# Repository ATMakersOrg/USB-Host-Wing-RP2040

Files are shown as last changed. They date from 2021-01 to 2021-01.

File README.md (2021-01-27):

# USB-Host-Wing-RP2040
 Prototype of a USB Host Feather Wing using the RP2040
 
 Based on the excellent Feather board by Limor Fried and quite unlikely to work at the moment.  This is just a starting point to see where this could go.  
 
# Goals
 * Board should run TinyUSB (probably through Arduino when that works) to host USB peripherals.
 * Logic on this board would read the USB and then send messages to the main feather via UART (by default) or I2C or SPI with appropriate solder jumpers set
 * Voltage on the USB Host port should be 5V even when the Feather is being powered by a battery, so an onboard boost converter is needed.
 
# Current Challenges
  * Layout is ineffecient (and there are probably conflicts, etc.
  * Room in the center could be used to expose additional GPIO or Analog pins (which would be handy)
  * It would be nice to have second rows of headers to allow connections from GPIO on this wing to the main feather.
  * Power on the USB-C connector is probably wrong... I need to think through how to handle programming vs hosting w/it.
  * The Boost converter I found (PCA9411) has a BGA package which would be hard to solder (and I know nothing about it) - looking to replace with MCP1642B-50 which is easier to solder & seems like a better fit.
  * The MISO and MOSI lines should not be swapped ( need to redo them)
 
 I welcome all input (including thoughts about killing this idea)!
 Bill
 
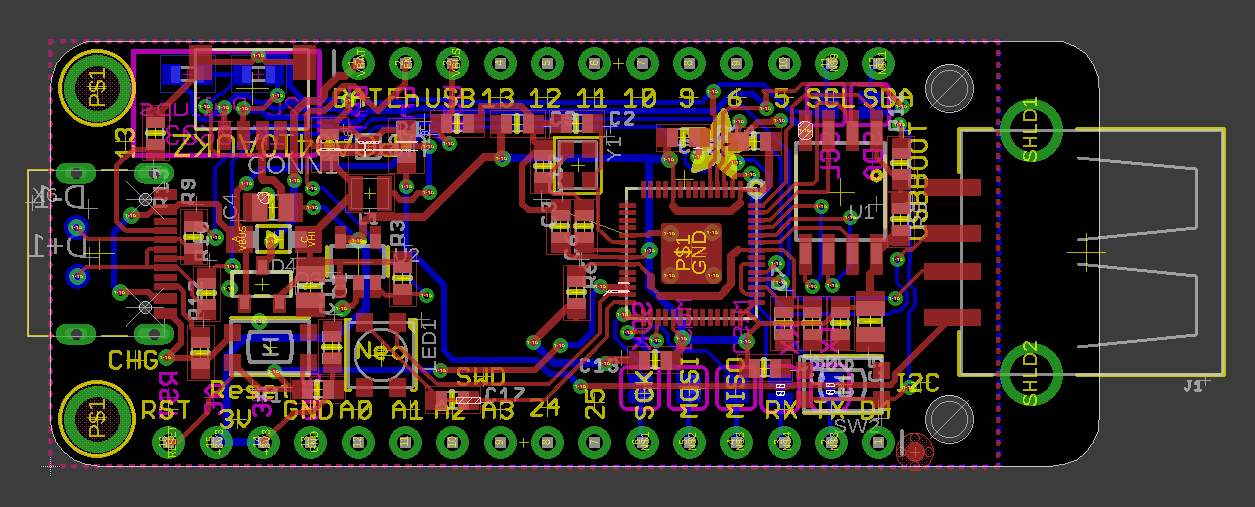
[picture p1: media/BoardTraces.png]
Board File

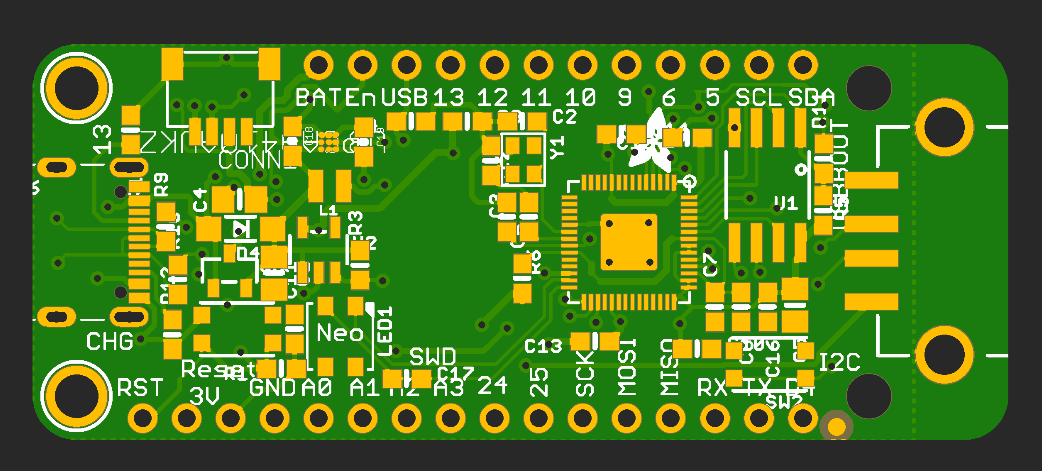
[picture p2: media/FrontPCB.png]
Top

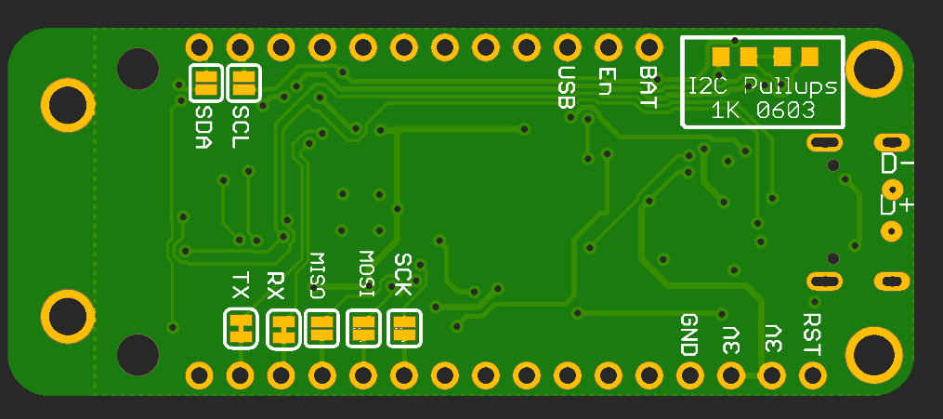
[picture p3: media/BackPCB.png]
Bottom

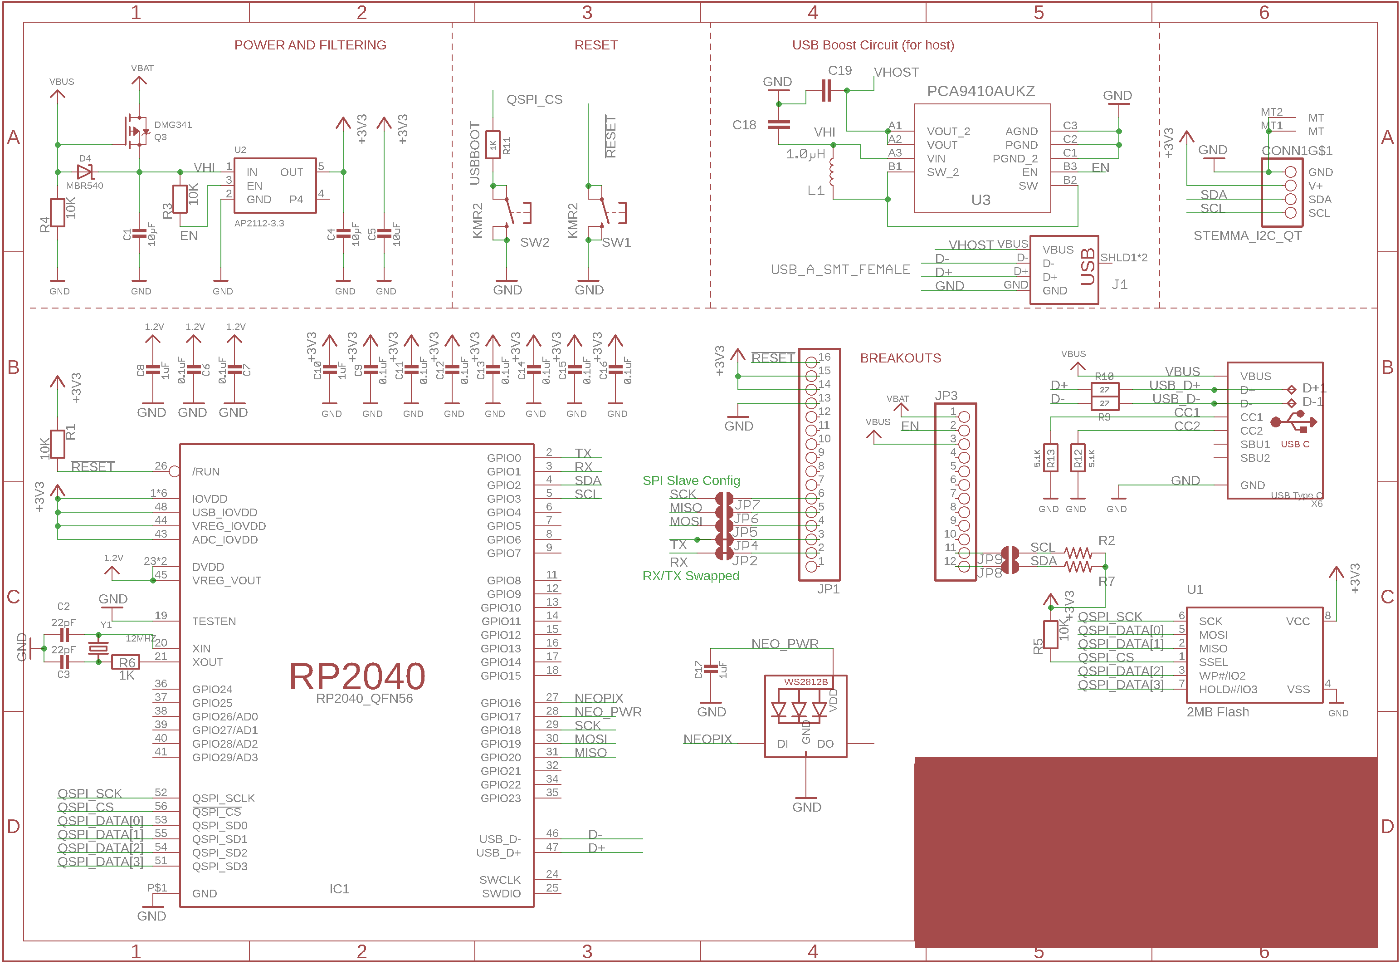
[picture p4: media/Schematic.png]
Schematic


NOTE: Images are likely out of date - check out the Eagle Files

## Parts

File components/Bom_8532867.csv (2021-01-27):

Manufacturer Part Number | Manufacturer | Digi-Key Part Number | Customer Reference | Reference Designator | Packaging | Part Status | Quantity | Unit Price | Extended Price | Quantity Available | Mfg Std Lead Time | Description | RoHS Status | Lead Free Status | REACH Status
B82462G4472M000 | EPCOS - TDK Electronics | 495-1997-1-ND | L1 |  | Cut Tape (CT) | Active | 1 | 1.68000 | $1.68 | 3916 | 10 Weeks | FIXED IND 4.7UH 2A 40 MOHM SMD | ROHS3 Compliant | Lead free | REACH Unaffected
7447785004 | Würth Elektronik | 732-4126-1-ND | L1 |  | Cut Tape (CT) | Active | 1 | 2.36000 | $2.36 | 965 | 18 Weeks | FIXED IND 4.7UH 2.65A 78 MOHM | ROHS3 Compliant | Lead free | REACH Unaffected
744052005 | Würth Elektronik | 732-1031-1-ND | L1 |  | Cut Tape (CT) | Active | 1 | 1.43000 | $1.43 | 4222 | 12 Weeks | FIXED IND 5UH 1.65A 60 MOHM SMD | ROHS3 Compliant | Lead free | REACH Unaffected
744042004 | Würth Elektronik | 732-1021-1-ND | L1 |  | Cut Tape (CT) | Active | 1 | 1.43000 | $1.43 | 6573 | 12 Weeks | FIXED IND 4.7UH 1.72A 82 MOHM | ROHS3 Compliant | Lead free | REACH Unaffected
744025004 | Würth Elektronik | 732-2615-1-ND | L1 |  | Cut Tape (CT) | Active | 1 | 1.54000 | $1.54 | 5982 | 12 Weeks | FIXED IND 4.7UH 1.35A 120 MOHM | ROHS3 Compliant | Lead free | REACH Unaffected
MCP1642B-50I/MS | Microchip Technology | MCP1642B-50I/MS-ND | U4 |  | Tube | Active | 1 | 1.03000 | $1.03 | 138 | 16 Weeks | IC REG BOOST 5V 800MA 8MSOP | ROHS3 Compliant | Lead free | REACH Unaffected

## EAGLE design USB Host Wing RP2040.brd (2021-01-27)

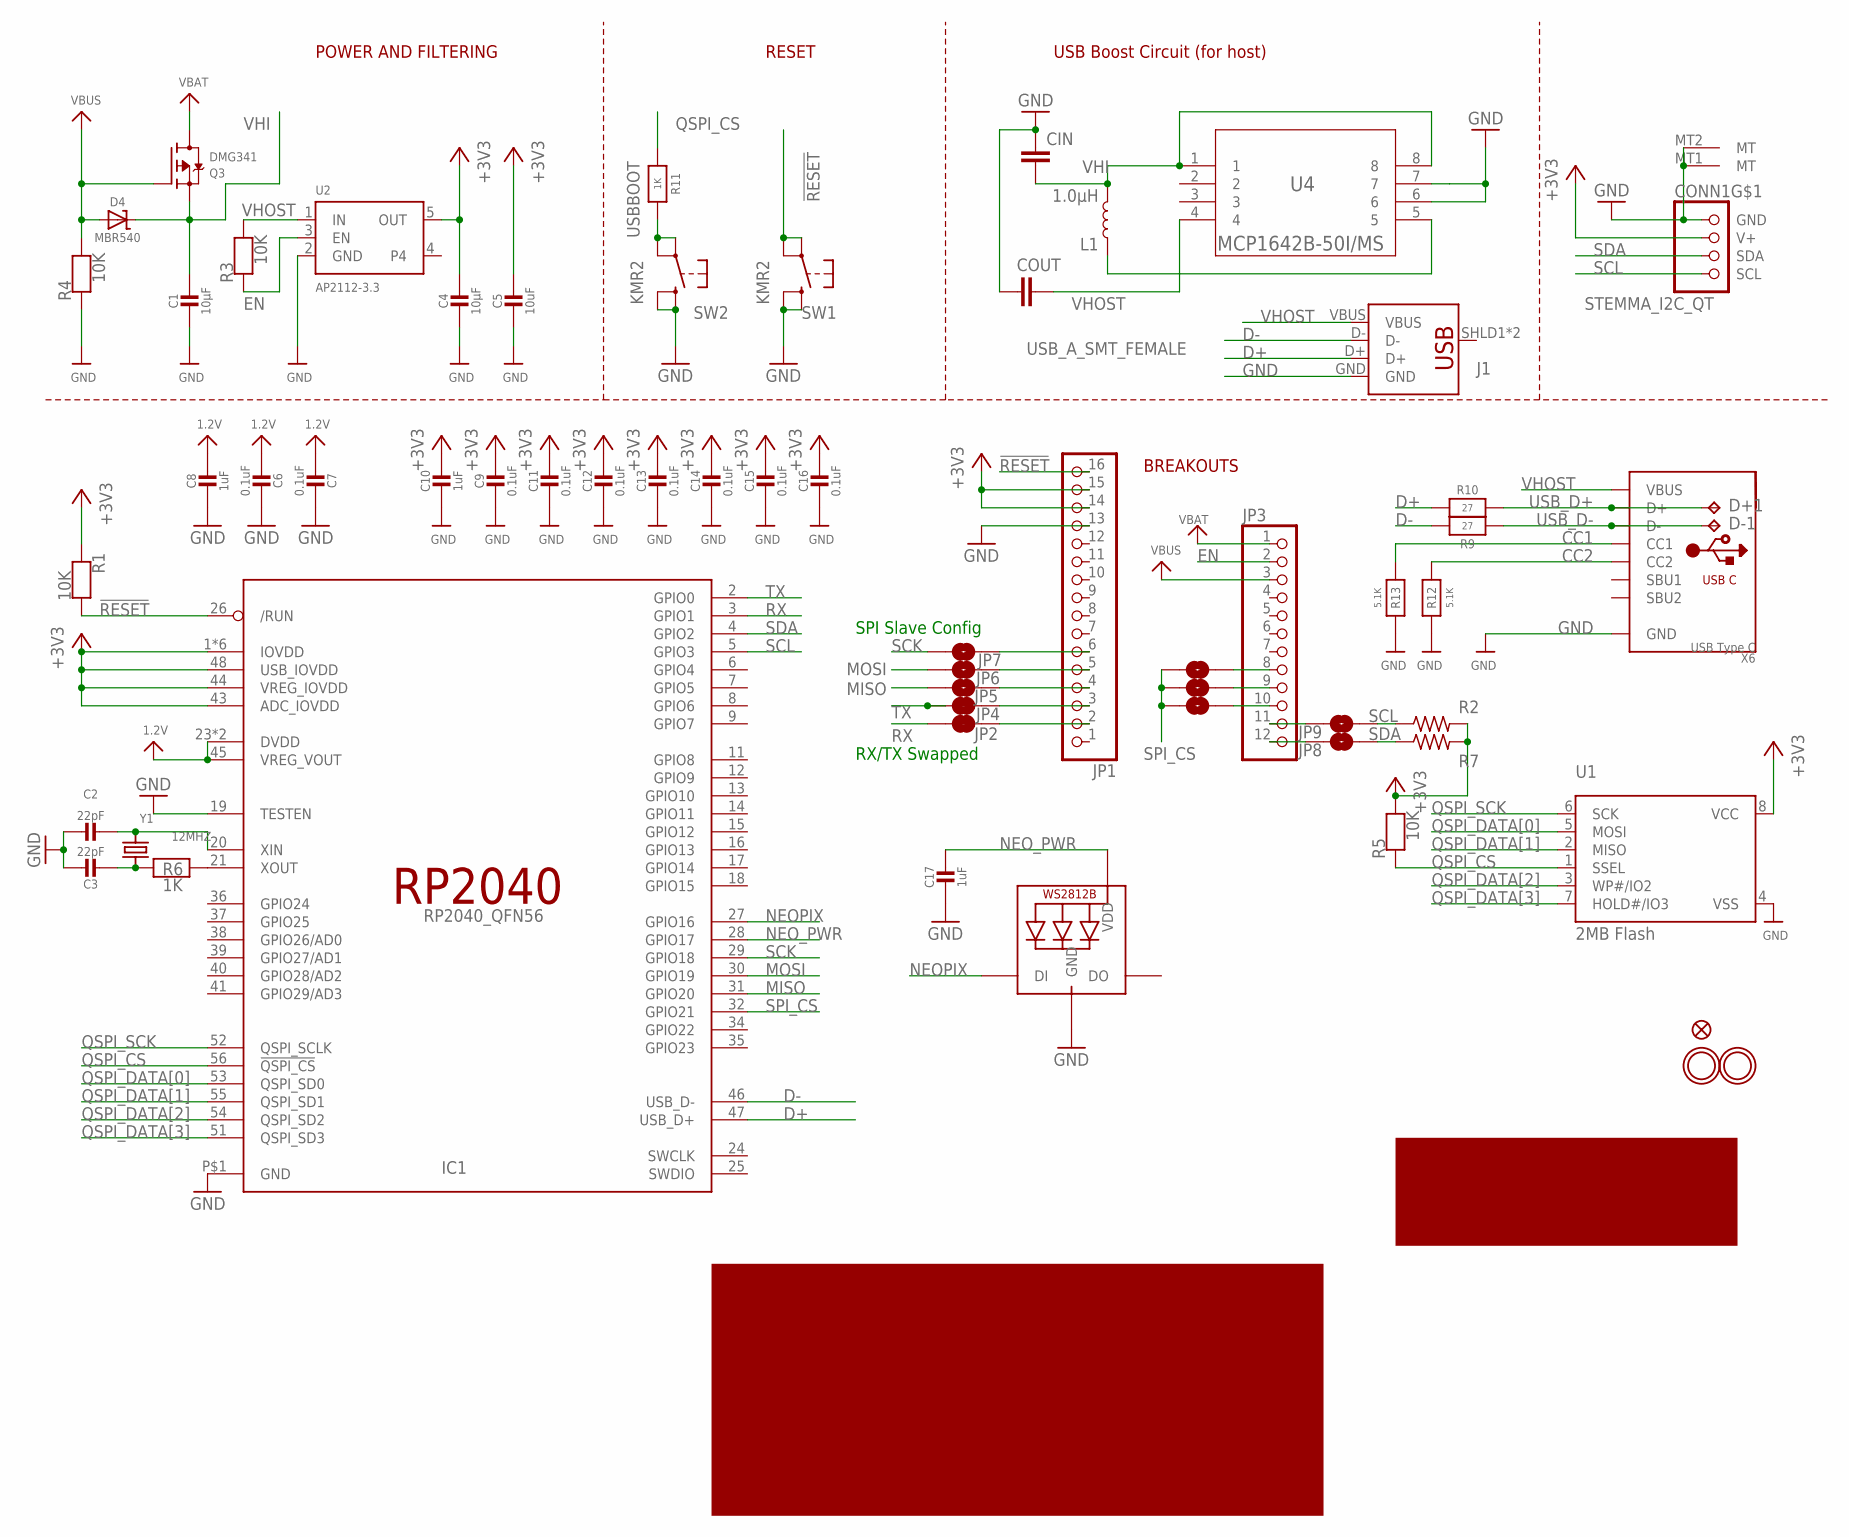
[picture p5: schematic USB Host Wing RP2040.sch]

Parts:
C1, C4: 10µF; 0805-NO
C2, C3: 22pF; 0603-NO
C5: 10uF; 0805-NO
C6, C7, C9, C11, C12, C13, C14, C15, C16: 0.1uF; 0603-NO
C8, C10, C17: 1uF; 0603-NO
CIN: SPARKFUN_CAP0603-CAP; SPARKFUN_0603-CAP
CONN1: STEMMA_I2C_QT; JST_SH4
COUT: SPARKFUN_CAP0603-CAP; SPARKFUN_0603-CAP
D4: MBR540; SOD-123
D+1: TPB1,27; B1,27
D-1: TPB1,27; B1,27
IC1: RP2040_QFN56; QFN56_7MM_REDUCEDEPAD
J1: USB_A_SMT_FEMALE; USB-A-S-SILK-FEMALE
JP1: HEADER-1X16ROUND; 1X16_ROUND
JP2, JP4: JUMPER-SMT_2_NC_TRACE_SILK; SMT-JUMPER_2_NC_TRACE_SILK
JP3: HEADER-1X12; 1X12_ROUND
JP5, JP6, JP7, JP8, JP9, JP10, JP11, JP12: JUMPER-SMT_2_NO_SILK; SMT-JUMPER_2_NO_SILK
L1: 1.0μH; 0805-WIDE
LED1: WS2812B3535; LED3535
Q3: DMG341; SOT23-R
R1, R3, R4, R5: 10K; 0603-NO
R2, R7: R-US_R0603; R0603
R6, R11: 1K; 0603-NO
R9, R10: 27; 0603-NO
R12, R13: 5.1K; 0603-NO
SW1, SW2: KMR2; BTN_KMR2_4.6X2.8
U1: 2MB Flash; SOIC8_208MIL
U2: AP2112-3.3; SOT23-5@1
U4: MCP1642B-50I/MS; MSOP8_MCP1642B-50I/MS_MCH
U$31, U$32: MOUNTINGHOLE2.5; MOUNTINGHOLE_2.5_PLATED
U$35: FIDUCIAL_1MM
X6: USB Type C; USB_C_CUSB31-CFM2AX-01-X
Y1: 12MHZ; CRYSTAL_2.5X2

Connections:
1.2V: C6.2, C7.2, C8.1, IC1.23 (DVDD), IC1.45 (VREG_VOUT), IC1.50 (DVDD)
!RESET: IC1.26 (/RUN), JP1.16, R1.2, SW1.A, SW1.A' (P1)
+3V3: C4.1, C5.1, C9.1, C10.1, C11.1, C12.1, C13.1, C14.1, C15.1, C16.1, CONN1.2 (V+), IC1.1 (IOVDD), IC1.10 (IOVDD), IC1.22 (IOVDD), IC1.33 (IOVDD), IC1.42 (IOVDD), IC1.43 (ADC_IOVDD), IC1.44 (VREG_IOVDD), IC1.48 (USB_IOVDD), IC1.49 (IOVDD), JP1.14, JP1.15, R1.1, R2.2, R5.2, R7.2, U1.8 (VCC), U2.5 (OUT)
CC1: R13.2, X6.A5 (CC1)
CC2: R12.2, X6.B5 (CC2)
D+: IC1.47 (USB_D+), J1.D+, R10.2
D-: IC1.46 (USB_D-), J1.D-, R9.2
EN: JP3.2, R3.1, U2.3 (EN)
GND: C1.2, C2.1, C3.1, C4.2, C5.2, C6.1, C7.1, C8.2, C9.2, C10.2, C11.2, C12.2, C13.2, C14.2, C15.2, C16.2, C17.2, CIN.1, CONN1.1 (GND), CONN1.MT1 (MT), CONN1.MT2 (MT), COUT.1, IC1.19 (TESTEN), IC1.P$1 (GND), J1.GND, JP1.13, LED1.4 (GND), R4.1, R12.1, R13.1, SW1.B (S), SW1.B' (S1), SW2.B (S), SW2.B' (S1), U1.4 (VSS), U2.2 (GND), U4.6, U4.7, X6.A1B12 (GND), X6.B1A12 (GND)
MISO: IC1.31 (GPIO20), JP5.1
MOSI: IC1.30 (GPIO19), JP6.1
unnamed: JP1.6, JP7.2
unnamed: JP1.5, JP6.2
unnamed: JP1.4, JP5.2
unnamed: JP1.3, JP4.2
unnamed: C2.2, IC1.20 (XIN), Y1.3 (2)
unnamed: C3.2, R6.1, Y1.1
unnamed: IC1.21 (XOUT), R6.2
unnamed: JP1.2, JP2.2
unnamed: JP3.11, JP9.1
unnamed: L1.1, U4.5
unnamed: JP3.12, JP8.1
unnamed: JP3.8, JP12.2
unnamed: JP3.9, JP11.2
unnamed: JP3.10, JP10.2
NEOPIX: IC1.27 (GPIO16), LED1.1 (DI)
NEO_PWR: C17.1, IC1.28 (GPIO17), LED1.2 (VDD)
QSPI_CS: IC1.56 (!QSPI_CS), R5.1, R11.1, U1.1 (SSEL)
QSPI_DATA[0]: IC1.53 (QSPI_SD0), U1.5 (MOSI)
QSPI_DATA[1]: IC1.55 (QSPI_SD1), U1.2 (MISO)
QSPI_DATA[2]: IC1.54 (QSPI_SD2), U1.3 (WP#/IO2)
QSPI_DATA[3]: IC1.51 (QSPI_SD3), U1.7 (HOLD#/IO3)
QSPI_SCK: IC1.52 (QSPI_SCLK), U1.6 (SCK)
RX: IC1.3 (GPIO1), JP2.1
SCK: IC1.29 (GPIO18), JP7.1
SCL: CONN1.4 (SCL), IC1.5 (GPIO3), JP9.2, R2.1
SDA: CONN1.3 (SDA), IC1.4 (GPIO2), JP8.2, R7.1
SPI_CS: IC1.32 (GPIO21), JP10.1, JP11.1, JP12.1
TX: IC1.2 (GPIO0), JP4.1
USBBOOT: R11.2, SW2.A, SW2.A' (P1)
USB_D+: D+1.TP, R10.1, X6.A6 (D+), X6.B6 (D+)
USB_D-: D-1.TP, R9.1, X6.A7 (D-), X6.B7 (D-)
VBAT: JP3.1, Q3.3 (D)
VBUS: D4.A, JP3.3, Q3.1 (G), R4.2
VHI: C1.1, CIN.2, D4.C, L1.2, Q3.2 (S), U4.1, U4.8
VHOST: COUT.2, J1.VBUS, R3.2, U2.1 (IN), U4.4, X6.A4B9 (VBUS), X6.B4A9 (VBUS)

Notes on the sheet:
POWER AND FILTERING
RESET
USB Boost Circuit (for host)
BREAKOUTS
RX/TX Swapped
SPI Slave Config

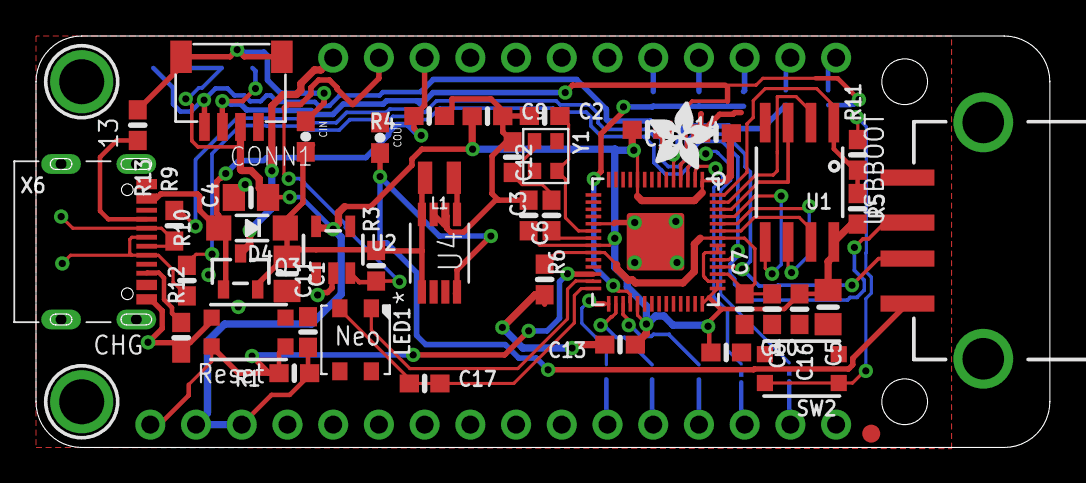
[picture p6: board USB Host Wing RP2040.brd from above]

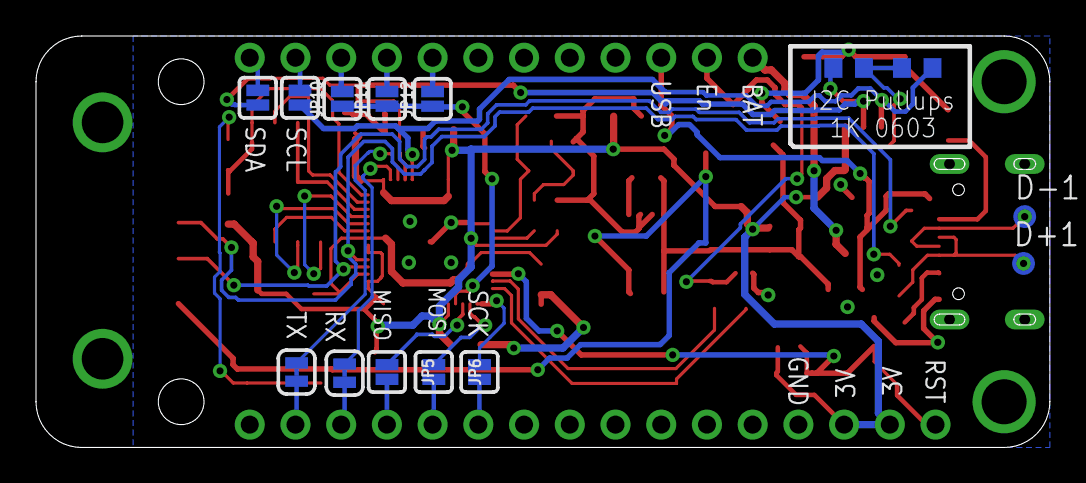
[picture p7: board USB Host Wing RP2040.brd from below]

Board: 2 copper layers, 56.3 x 22.9 mm, 63 parts (14 on the bottom side), 46 nets.

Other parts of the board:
U$28: ADAFRUIT_3.5MM

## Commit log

2021-01-26 Continued fixes
    Modified to replace the boost converter and fix the MOSI/MISO issue. Also added CS jumpers for SPI users.
    Still has air wires & issues.
    [USB Host Wing RP2040.brd, USB Host Wing RP2040.sch]
2021-01-26 Update for John
    [USB Host Wing RP2040.brd, USB Host Wing RP2040.sch]
2021-01-27 Changed source of linear regulator to VHOST
    [USB Host Wing RP2040.brd, USB Host Wing RP2040.sch]

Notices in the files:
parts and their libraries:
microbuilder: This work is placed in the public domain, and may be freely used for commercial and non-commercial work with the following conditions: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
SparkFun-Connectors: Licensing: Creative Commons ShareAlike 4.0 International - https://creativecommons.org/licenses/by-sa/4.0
